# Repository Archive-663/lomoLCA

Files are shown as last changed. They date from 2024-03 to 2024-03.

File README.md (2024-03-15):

# Lot no. 016 | A rehousing Lomo LC-A 32mm Minitar lens for mirrorless

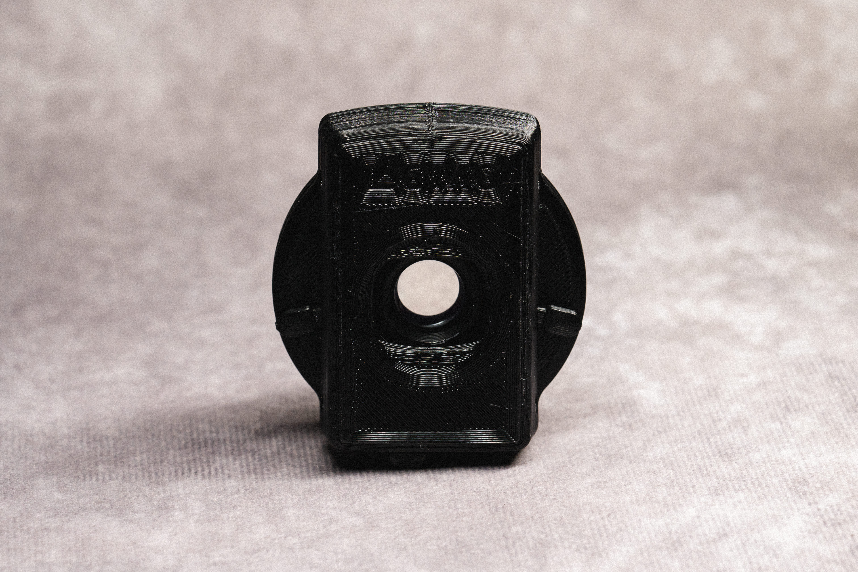
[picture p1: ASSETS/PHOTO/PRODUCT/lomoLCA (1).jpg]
productPhoto001

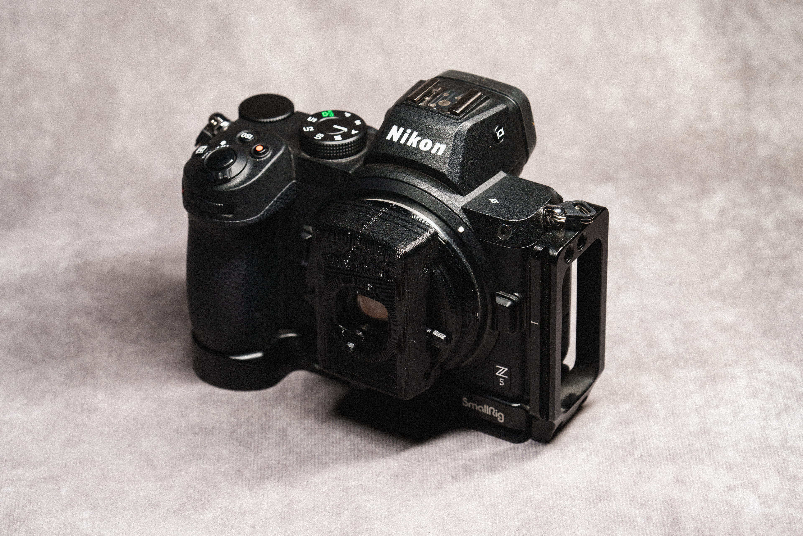
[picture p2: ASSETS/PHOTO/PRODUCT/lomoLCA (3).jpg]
productPhoto002

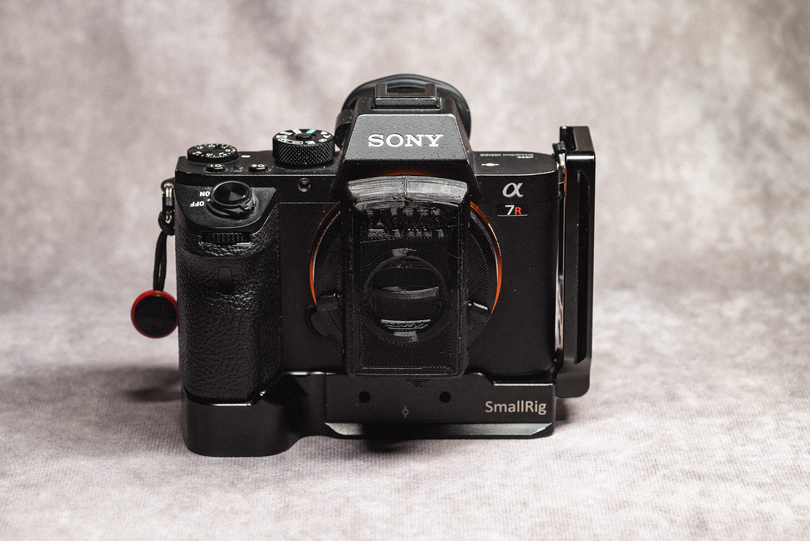
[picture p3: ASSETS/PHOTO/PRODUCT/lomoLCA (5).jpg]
productPhoto003

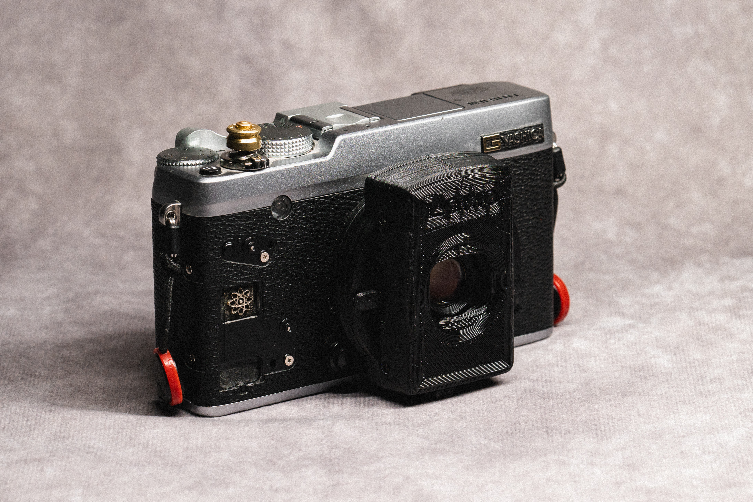
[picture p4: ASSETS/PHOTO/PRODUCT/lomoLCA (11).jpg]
productPhoto004


### In this repository:
- [Lomo LC-A Main Rehousing](https://github.com/Archive-663/lomoLCA/tree/main/Lomo%20LCA%20Main%20Rehousing)
- [Sony E-Mount](https://github.com/Archive-663/lomoLCA/tree/main/Sony%20E-mount)
- [Canon RF-Mount](https://github.com/Archive-663/lomoLCA/tree/main/Canon%20RF-mount)
- [Fuji X-Mount](https://github.com/Archive-663/lomoLCA/tree/main/Fuji%20X-mount)
- [Nikon Z-Mount](https://github.com/Archive-663/lomoLCA/tree/main/Nikon%20Z-mount)

### How to use this Repo:
Download the Main Housing and then the mount you have. You can pick up <a href="https://github.com/Archive-663/lensMounts" target='_blank'>rear lens caps here.</a>

### Accompanying video:
<a href='https://www.youtube.com/watch?v=eCiiPDMJ1F8' target='_blank'>004 / / the one where i ask you to come back here at six in the morning and call my name twice</a>

### Background Story:
I always liked the camera body of the Lomo LC-A and I didn't enjoy how expensive the Lomography Minitar lens was. I wanted to replicate the experience of shooting with the LC-A with sliding lens cover, and lever acuated aperture and focus. I picked up a lens assembly from a broken LC-A and started working on translating the LC-A's sliding lens cover and once I figured that out I applied the same assembly to the aperture as space was limited. I could have easily made an iris but there was not enough room to allow for multiple mounts.

If you have a broken LC-A you can put the lens to good use now with this rehousing. It's a pretty simple print with minimal post processing.

### Samples:
samplePhoto001
samplePhoto002
samplePhoto003
samplePhoto004

### Help support Archive 663 with a dontation or monthly sub



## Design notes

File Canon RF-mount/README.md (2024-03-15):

# Lot no. 016 | Lomo LC-A Canon RF-Mount

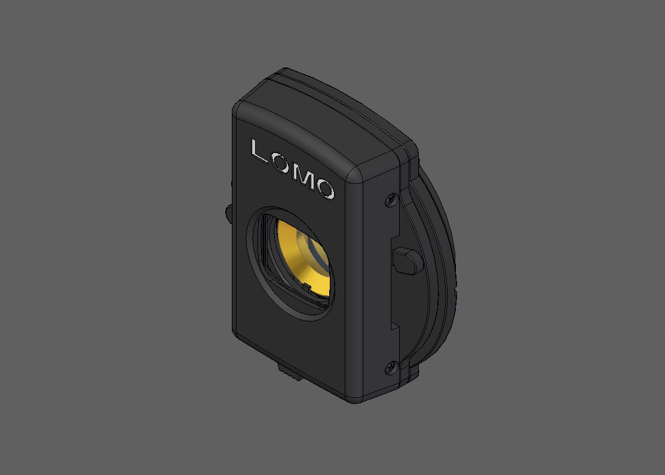
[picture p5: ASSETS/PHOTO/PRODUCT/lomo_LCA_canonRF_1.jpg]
productPhoto001

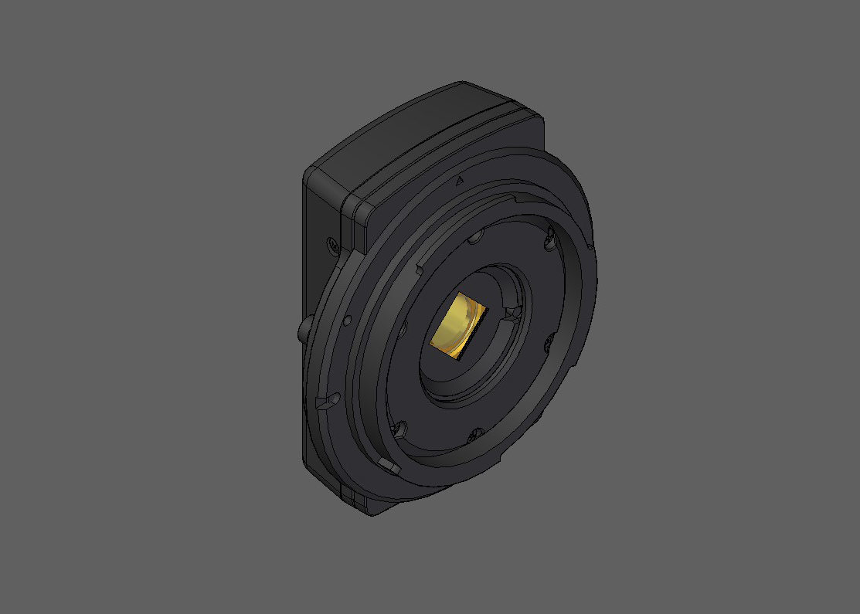
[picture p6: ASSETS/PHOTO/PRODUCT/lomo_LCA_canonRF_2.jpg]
productPhoto002


### What you'll need:
- 6x M1.6 x 5mm pan head screws (PETG) or self-tappin screws (ABS or PETG)
- 1x M1.6 tap

### What would be helpful:
- M1.4 drill bit
- M1.8/M2 drill bit
- Micro files
- PTFE synthetic grease

### Printing help:
Filament recommendation:
- ABS
- PETG

Generally, all my designs have chamfers on the print face of the STL. You can reference the supplied 'printOrientationFile.3mf' files for suggested print orientation.

### Assembly help:
Drill holes to their correct tap size before tapping.
- M1.6 requires M1.4 bore followed by an M1.6 tap.
- M1.8 or M2 bore for screw holes that aren't tapped.

- Specifically for the Canon RF mount you need to replace the 'lensBase_Mount' with the 'canonRF_mount'

Test fit before assembling. Will need to file parts to allow free movement. You may need to drill out the original mounting holes on the Minitar lens assembly for the m1.6 screws to fit. 

Lightly grease the inside of the mount cap.

To assemble correctly, please view the _assembly.stp file for help in parts orientation. If you do not have a CAD program, <a href="https://www.freecad.org/downloads.php" target="_blank">download FreeCAD</a> to view the assembly file and better understand how it should assemble. If using FreeCAD, the naming conventions should carry over and you will be able to see which lens element you need from the various smartphone lenses. (Verified in FreeCAD 0.18) If using something like Solid Edge open the file as an assembly to retain the names of the parts.

### Help support Archive 663 with a dontation or monthly sub



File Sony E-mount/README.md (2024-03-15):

# Lot no. 016 | Lomo LC-A Sony E-Mount

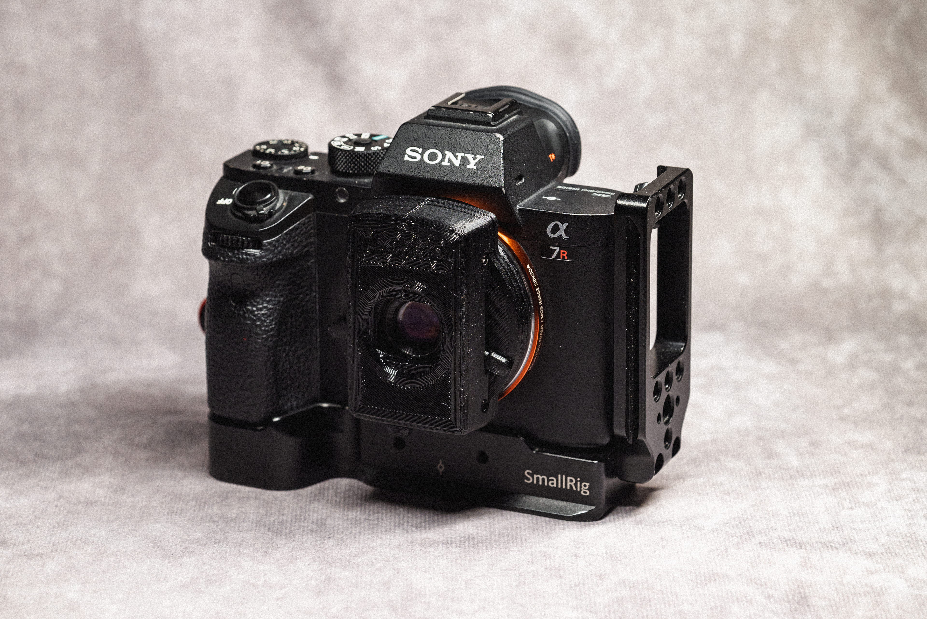
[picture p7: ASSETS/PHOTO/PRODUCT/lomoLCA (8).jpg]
productPhoto001

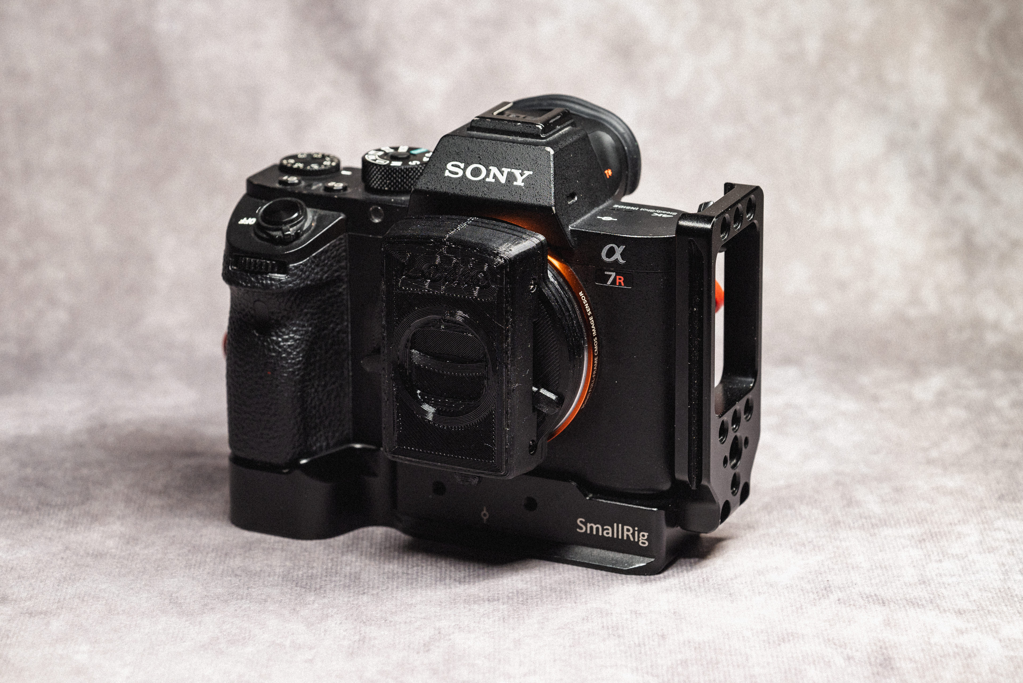
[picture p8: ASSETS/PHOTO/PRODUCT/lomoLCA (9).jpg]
productPhoto002


### What you'll need:
- 6x M1.6 x 5mm pan head screws (PETG) or self-tappin screws (ABS or PETG)
- 1x M1.6 tap

### What would be helpful:
- M1.4 drill bit
- M1.8/M2 drill bit
- Micro files
- PTFE synthetic grease

### Printing help:
Filament recommendation:
- ABS
- PETG

Generally, all my designs have chamfers on the print face of the STL. You can reference the supplied 'printOrientationFile.3mf' files for suggested print orientation.

### Assembly help:
Drill holes to their correct tap size before tapping.
- M1.6 requires M1.4 bore followed by an M1.6 tap.
- M1.8 or M2 bore for screw holes that aren't tapped.

Test fit before assembling. Will need to file parts to allow free movement. You may need to drill out the original mounting holes on the Minitar lens assembly for the m1.6 screws to fit. 

Lightly grease the inside of the mount cap where the aperture clutch runs.

To assemble correctly, please view the _assembly.stp file for help in parts orientation. If you do not have a CAD program, <a href="https://www.freecad.org/downloads.php" target="_blank">download FreeCAD</a> to view the assembly file and better understand how it should assemble. If using FreeCAD, the naming conventions should carry over and you will be able to see which lens element you need from the various smartphone lenses. (Verified in FreeCAD 0.18) If using something like Solid Edge open the file as an assembly to retain the names of the parts.

### Help support Archive 663 with a dontation or monthly sub



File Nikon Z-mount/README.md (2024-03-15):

# Lot no. 016 | Lomo LC-A Nikon Z-Mount

productPhoto001
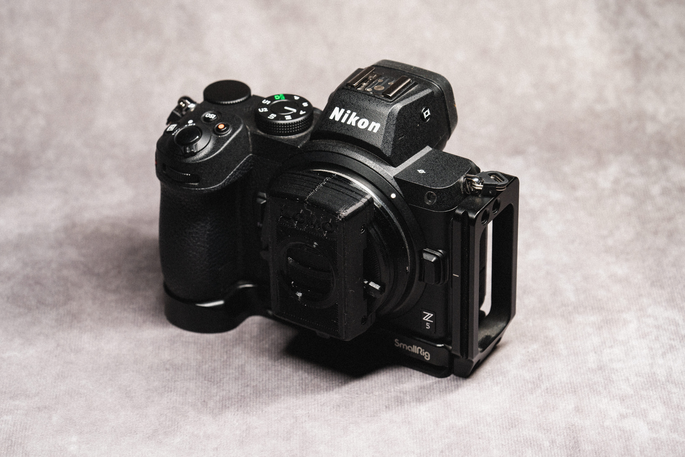
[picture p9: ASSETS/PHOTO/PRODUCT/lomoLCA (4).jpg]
productPhoto002


### What you'll need:
- 12x M1.6 x 5mm pan head screws (PETG) or self-tappin screws (ABS or PETG)
- 1x M1.6 tap

### What would be helpful:
- M1.4 drill bit
- M1.8/M2 drill bit
- Micro files
- PTFE synthetic grease

### Printing help:
Filament recommendation:
- ABS
- PETG

Generally, all my designs have chamfers on the print face of the STL. You can reference the supplied 'printOrientationFile.3mf' files for suggested print orientation.

### Assembly help:
Drill holes to their correct tap size before tapping.
- M1.6 requires M1.4 bore followed by an M1.6 tap.
- M1.8 or M2 bore for screw holes that aren't tapped.

Test fit before assembling. Will need to file parts to allow free movement. You may need to drill out the original mounting holes on the Minitar lens assembly for the m1.6 screws to fit. 

Lightly grease the inside of the mount where the aperture clutch runs.

To assemble correctly, please view the _assembly.stp file for help in parts orientation. If you do not have a CAD program, <a href="https://www.freecad.org/downloads.php" target="_blank">download FreeCAD</a> to view the assembly file and better understand how it should assemble. If using FreeCAD, the naming conventions should carry over and you will be able to see which lens element you need from the various smartphone lenses. (Verified in FreeCAD 0.18) If using something like Solid Edge open the file as an assembly to retain the names of the parts.

### Help support Archive 663 with a dontation or monthly sub



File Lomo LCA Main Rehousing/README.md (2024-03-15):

# Lot no. 016 | Lomo LC-A Main Rehousing

productPhoto001
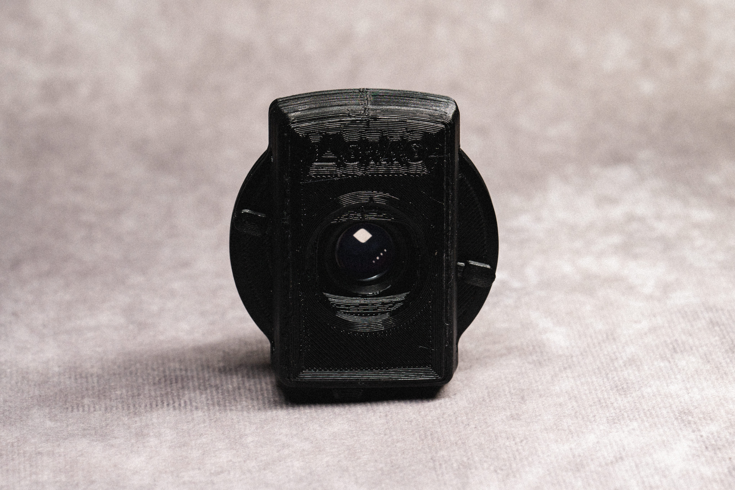
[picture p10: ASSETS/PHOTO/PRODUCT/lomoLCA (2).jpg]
productPhoto002

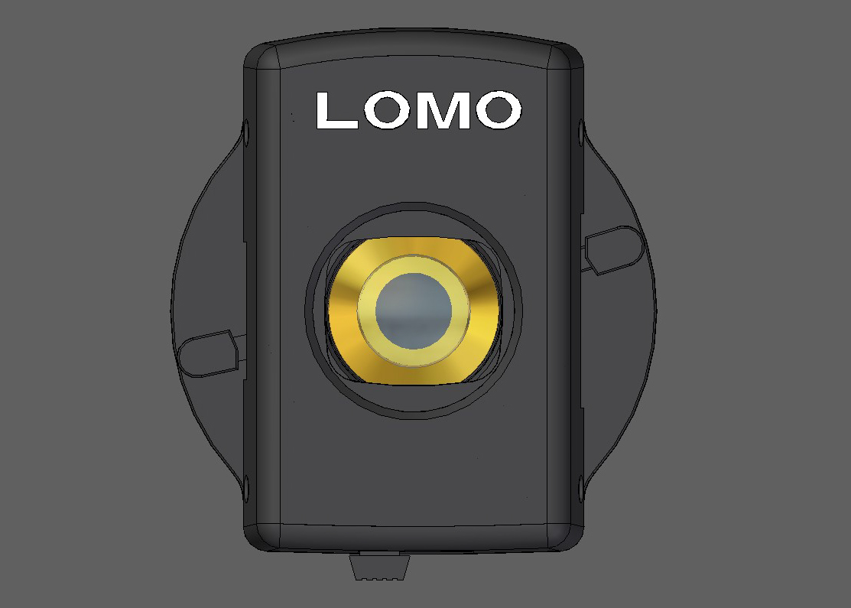
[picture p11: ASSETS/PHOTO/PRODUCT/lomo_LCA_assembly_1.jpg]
productPhoto003

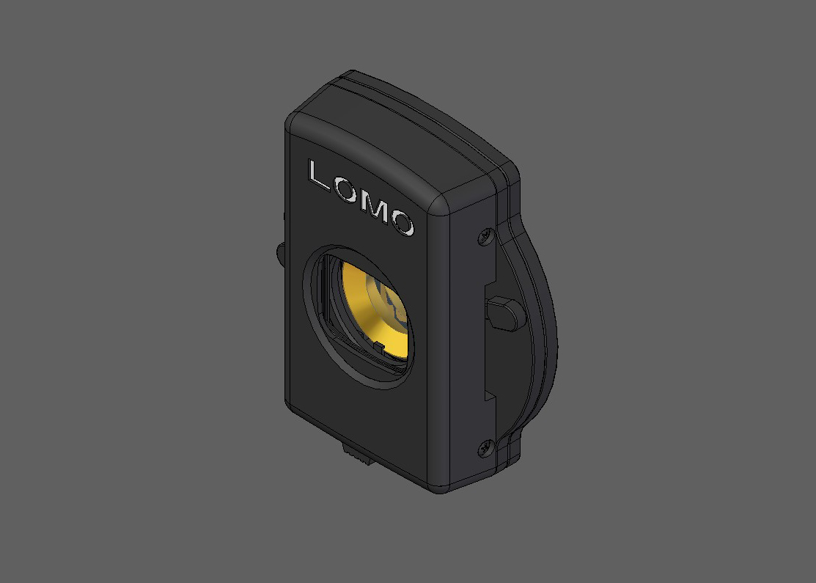
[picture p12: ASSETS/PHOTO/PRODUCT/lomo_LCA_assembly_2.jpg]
productPhoto004

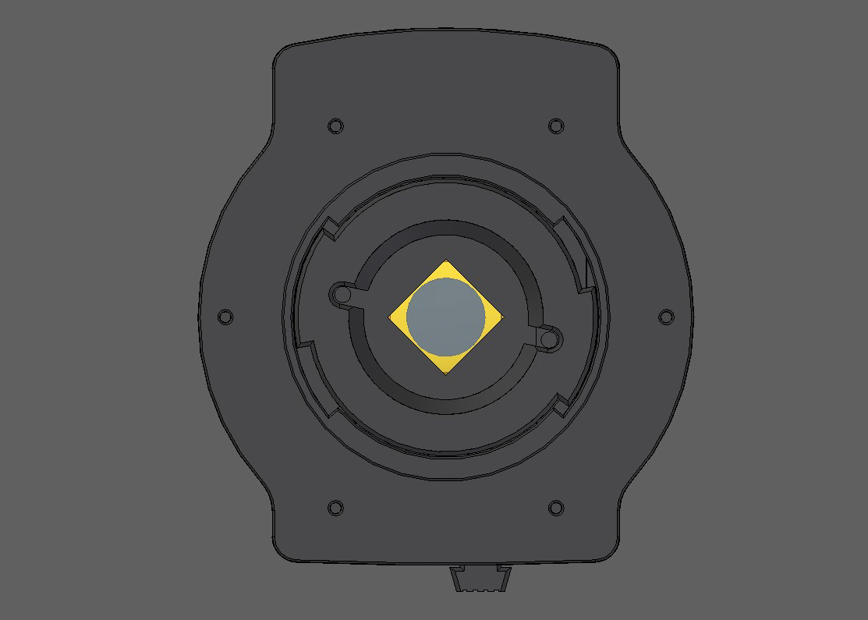
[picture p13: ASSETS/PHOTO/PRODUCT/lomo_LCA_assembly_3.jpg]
productPhoto005


### Features:
- Iconic Sliding Lens Cover
- Lever actuated Aperture and Focus
- Standard LOMO or classic ЛОМО face plate

### What you'll need:
- 15x M1.6 x 5mm pan head screws (PETG) or self-tappin screws (ABS or PETG)
- 1x M1.6 tap

### What would be helpful:
- M1.4 drill bit
- M1.8/M2 drill bit
- Micro files
- PTFE synthetic grease

### Printing help:
Filament recommendation:
- ABS
- PETG

Generally, all my designs have chamfers on the print face of the STL. You can reference the supplied 'printOrientationFile.3mf' files for suggested print orientation.

### Assembly help:
Drill holes to their correct tap size before tapping.
- M1.6 requires M1.4 bore followed by an M1.6 tap.
- M1.8 or M2 bore for screw holes that aren't tapped.

Test fit before assembling. Will need to file parts to allow free movement. You may need to drill out the original mounting holes on the Minitar lens assembly for the m1.6 screws to fit.

Lightly grease the shutter and aperture tracks and the blades.

To assemble correctly, please view the _assembly.stp file for help in parts orientation. If you do not have a CAD program, <a href="https://www.freecad.org/downloads.php" target="_blank">download FreeCAD</a> to view the assembly file and better understand how it should assemble. If using FreeCAD, the naming conventions should carry over and you will be able to see which lens element you need from the various smartphone lenses. (Verified in FreeCAD 0.18) If using something like Solid Edge open the file as an assembly to retain the names of the parts.

### Help support Archive 663 with a dontation or monthly sub



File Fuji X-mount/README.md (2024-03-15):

# Lot no. 016 | Lomo LC-A Fuji X-Mount

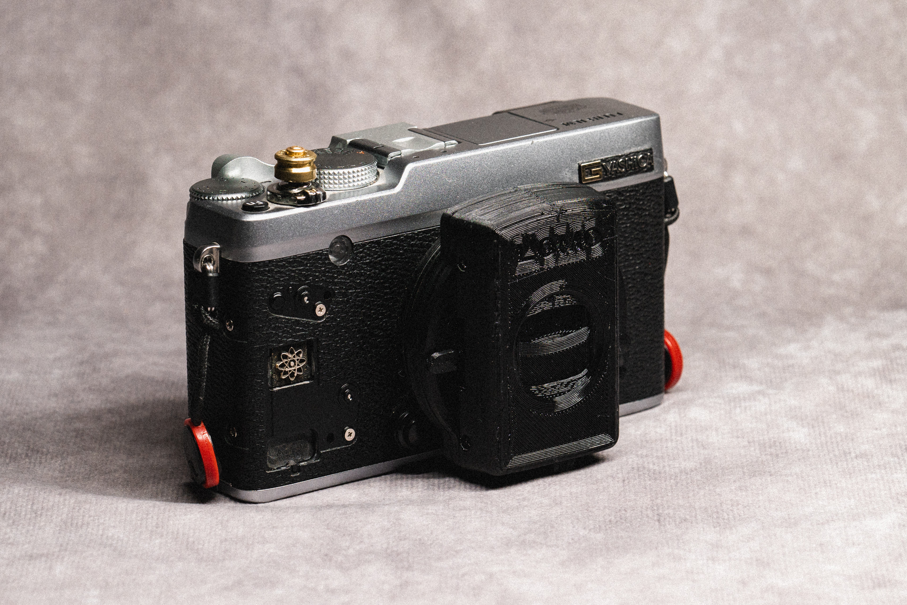
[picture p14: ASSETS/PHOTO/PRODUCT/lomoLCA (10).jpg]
productPhoto001

productPhoto002
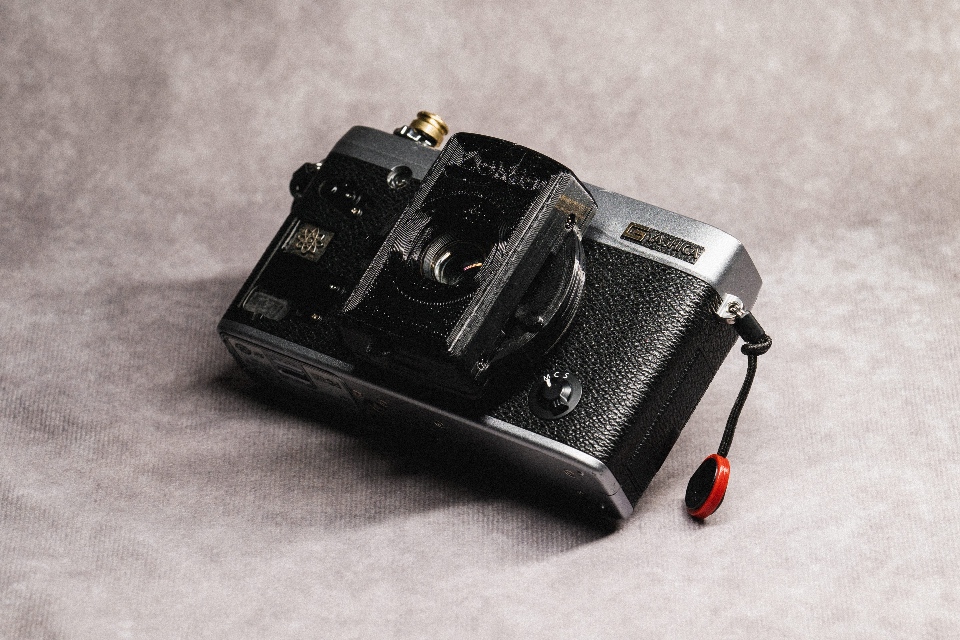
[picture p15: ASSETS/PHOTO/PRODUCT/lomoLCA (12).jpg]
productPhoto003

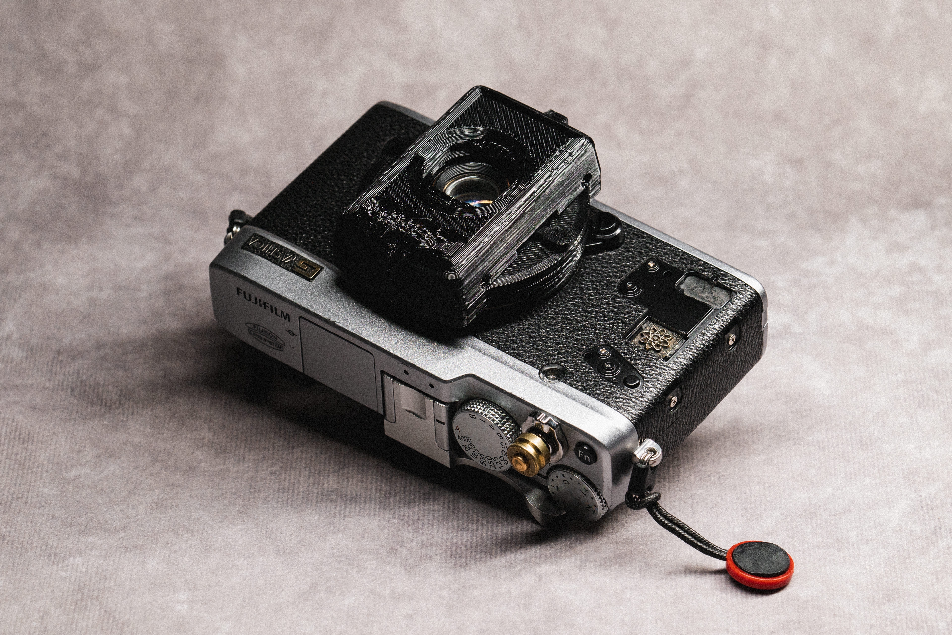
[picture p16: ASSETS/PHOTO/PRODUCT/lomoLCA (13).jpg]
productPhoto004


### What you'll need:
- 6x M1.6 x 5mm pan head screws (PETG) or self-tappin screws (ABS or PETG)
- 1x M1.6 tap

### What would be helpful:
- M1.4 drill bit
- M1.8/M2 drill bit
- Micro files
- PTFE synthetic grease

### Printing help:
Filament recommendation:
- ABS
- PETG

Generally, all my designs have chamfers on the print face of the STL. You can reference the supplied 'printOrientationFile.3mf' files for suggested print orientation.

### Assembly help:
Drill holes to their correct tap size before tapping.
- M1.6 requires M1.4 bore followed by an M1.6 tap.
- M1.8 or M2 bore for screw holes that aren't tapped.

Test fit before assembling. Will need to file parts to allow free movement. You may need to drill out the original mounting holes on the Minitar lens assembly for the m1.6 screws to fit. 

Lightly grease the inside of the mount where the aperture clutch runs.

To assemble correctly, please view the _assembly.stp file for help in parts orientation. If you do not have a CAD program, <a href="https://www.freecad.org/downloads.php" target="_blank">download FreeCAD</a> to view the assembly file and better understand how it should assemble. If using FreeCAD, the naming conventions should carry over and you will be able to see which lens element you need from the various smartphone lenses. (Verified in FreeCAD 0.18) If using something like Solid Edge open the file as an assembly to retain the names of the parts.

### Help support Archive 663 with a dontation or monthly sub



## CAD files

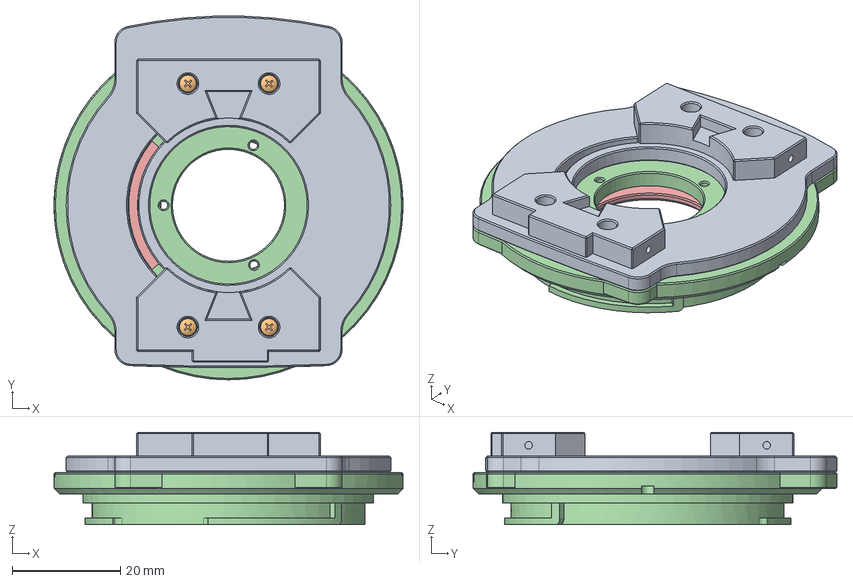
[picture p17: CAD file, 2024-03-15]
Canon RF-mount/STEP/lomo_LCA_canonRF_mount_assembly.stp
64.5 x 67.2 x 17.0 mm
lomo_LCA_lensBase
M1.6_panHead_5mm x 10
lomo_LCA_canonRF_mount

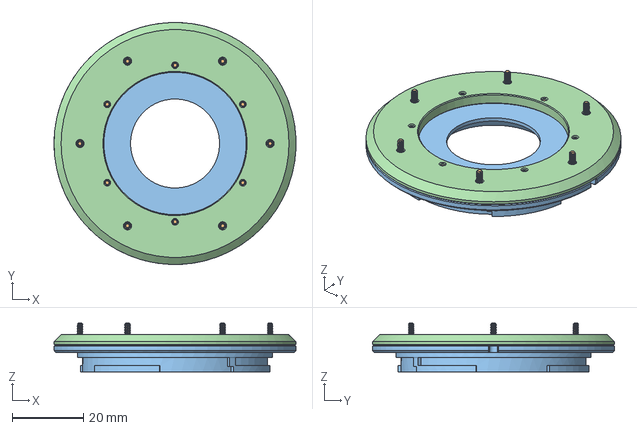
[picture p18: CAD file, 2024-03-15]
Nikon Z-mount/STEP/lomo_LCA_nikonZ_mount_assembly.stp
68.0 x 68.0 x 13.8 mm
M1.6_panHead_5mm x 12
lomo_LCA_nikonZ_mount

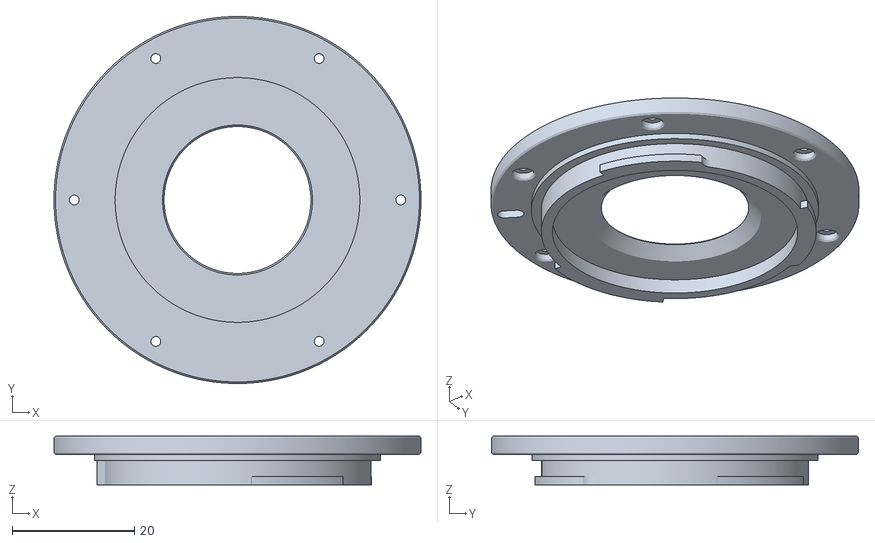
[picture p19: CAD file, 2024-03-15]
Sony E-mount/STL/lomo_LCA_sonyE_mount_complete.stl
60.0 x 60.0 x 8.00

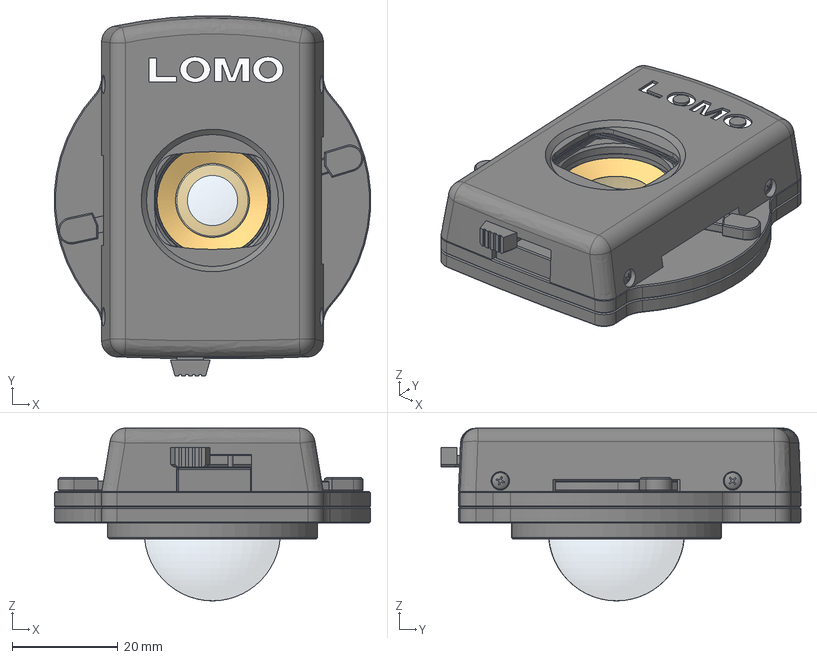
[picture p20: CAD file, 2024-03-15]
Lomo LCA Main Rehousing/STEP/lomo_LCA_assembly.stp
59.9 x 68.2 x 32.7 mm
lomo_LCA_lensMinitar
lomo_LCA_lensBase
M1.6_panHead_5mm x 15
lomo_LCA_focusRing
lomo_LCA_focusLock
lomo_LCA_apertureBlade_2
lomo_LCA_apertureBlade_1
lomo_LCA_apertureClutch
lomo_LCA_apertureLever
lomo_LCA_shutterTrack
lomo_LCA_lensBase_mount
lomo_LCA_shutterClutch
lomo_LCA_shutterClutchSlide
lomo_LCA_shutterTrack_cap
lomo_LCA_lensFacePlate_LOMO
lomo_LCA_lensShutter_1
lomo_LCA_lensShutter_2

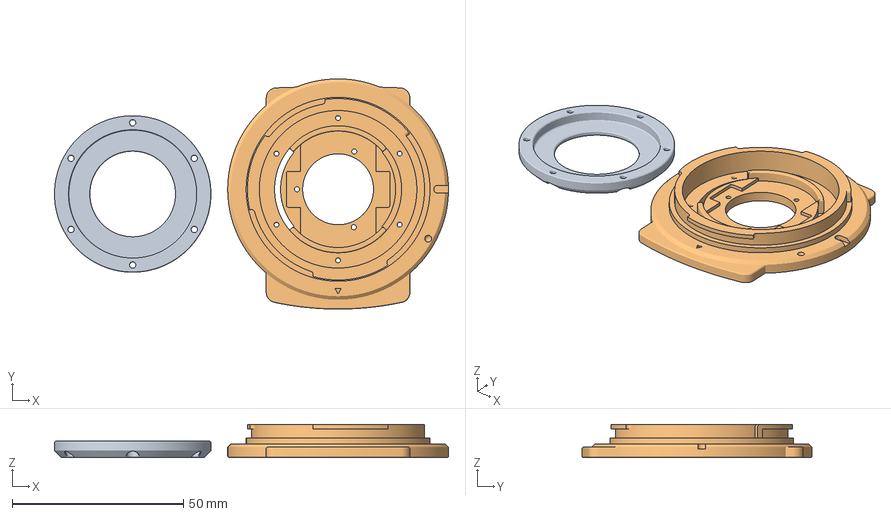
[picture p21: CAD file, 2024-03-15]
Canon RF-mount/STL/lomo_LCA_canonRF_mount_printOrientationFile.3mf
115.1 x 67.2 x 9.65 mm
lomo_LCA_canonRF_mount_cap.stl
lomo_LCA_canonRF_mount.stl

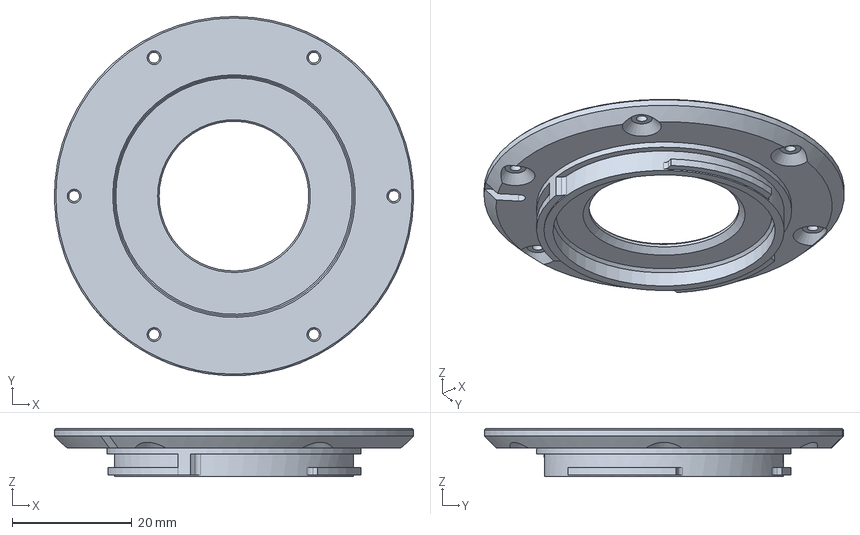
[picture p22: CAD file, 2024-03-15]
Fuji X-mount/STEP/lomo_LCA_fujiX_mount.stp
60.0 x 60.0 x 8.05 mm

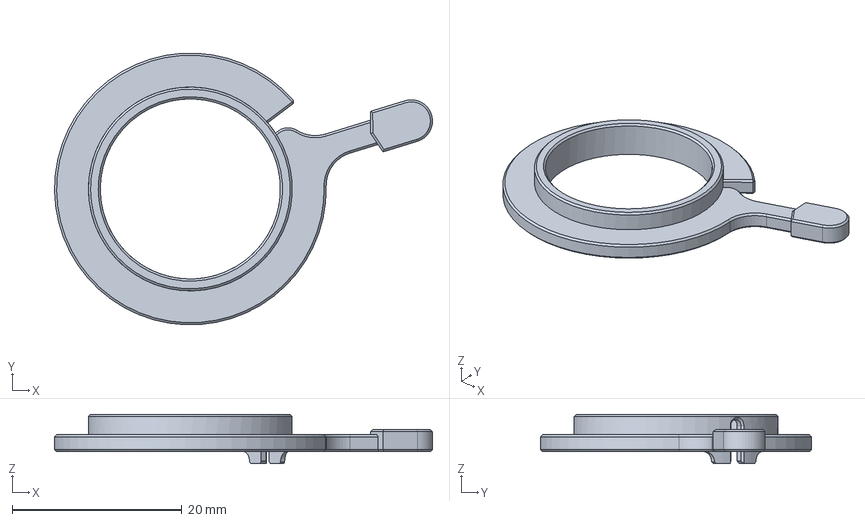
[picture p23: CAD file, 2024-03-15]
Lomo LCA Main Rehousing/STEP/lomo_LCA_focusRing.stp
44.5 x 32.0 x 5.83 mm

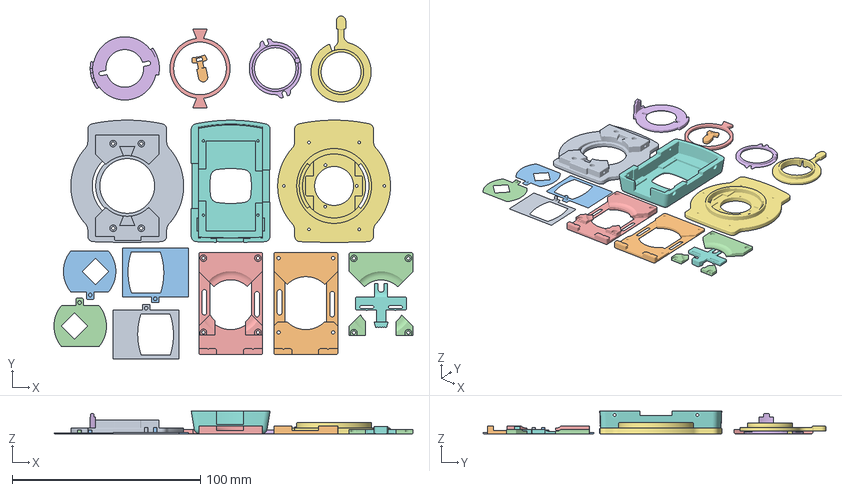
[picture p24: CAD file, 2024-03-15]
Lomo LCA Main Rehousing/STL/lomo_LCA_rehousing_printOrientationFile.3mf
190.9 x 182.4 x 12.0 mm
lomo_LCA_lensBase.stl
lomo_LCA_apertureLever.stl
lomo_LCA_apertureBlade_1.stl
lomo_LCA_apertureBlade_2.stl
lomo_LCA_focusLock.stl
lomo_LCA_apertureClutch.stl
lomo_LCA_focusRing.stl
lomo_LCA_shutterClutchSlide.stl
lomo_LCA_lensShutter_1.stl
lomo_LCA_shutterTrack_base.stl
lomo_LCA_lensShutter_2.stl
lomo_LCA_shutterTrack_cap.stl
lomo_LCA_shutterTrack.stl
lomo_LCA_shutterClutch.stl
lomo_LCA_lensBase_mount.stl
lomo_LCA_lensFacePlate_LOMO.stl

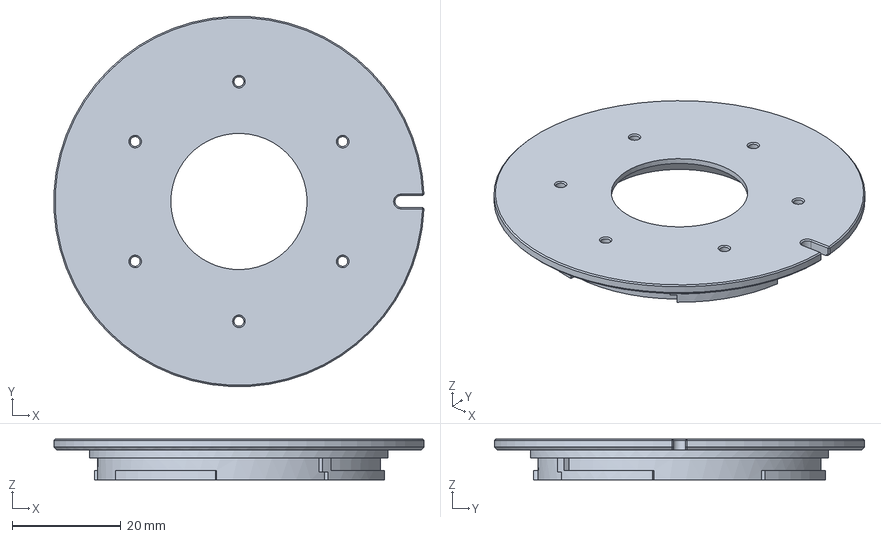
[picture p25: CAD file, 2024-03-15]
Nikon Z-mount/STEP/lomo_LCA_nikonZ_mount.stp
67.9 x 67.9 x 7.50 mm

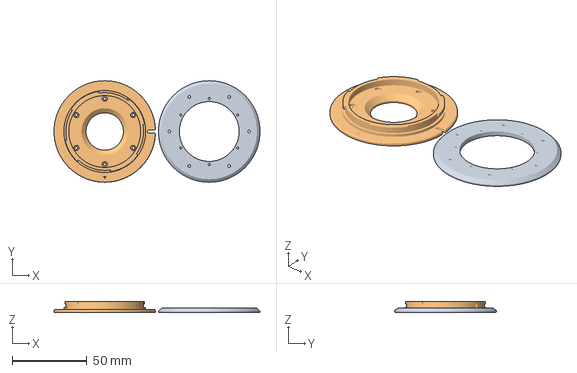
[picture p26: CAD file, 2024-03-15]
Nikon Z-mount/STL/lomo_LCA_nikonZ_mount_printOrientationFile.3mf
138.0 x 68.0 x 7.50 mm
lomo_LCA_nikonZ_cap.stl
lomo_LCA_nikonZ_mount.stl

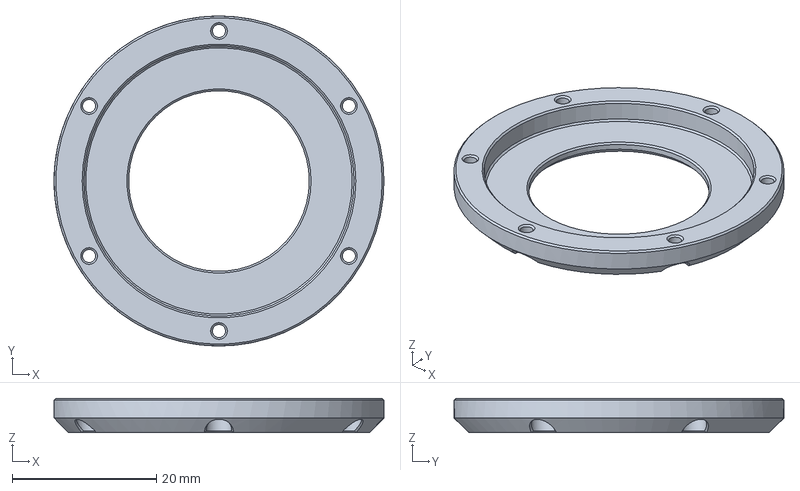
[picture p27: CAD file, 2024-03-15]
Canon RF-mount/STEP/lomo_LCA_canonRF_mount_cap.stp
45.7 x 45.7 x 4.75 mm

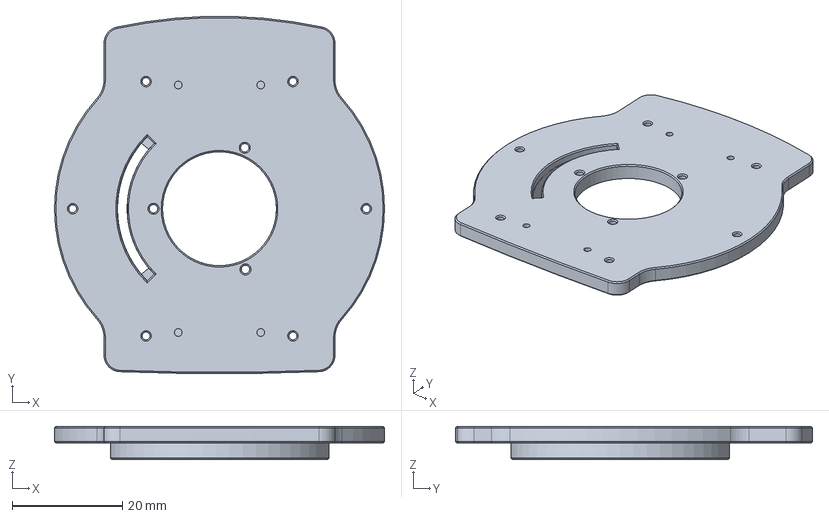
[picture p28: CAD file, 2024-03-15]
Lomo LCA Main Rehousing/STEP/lomo_LCA_lensBase_mount.stp
60.0 x 64.9 x 6.00 mm

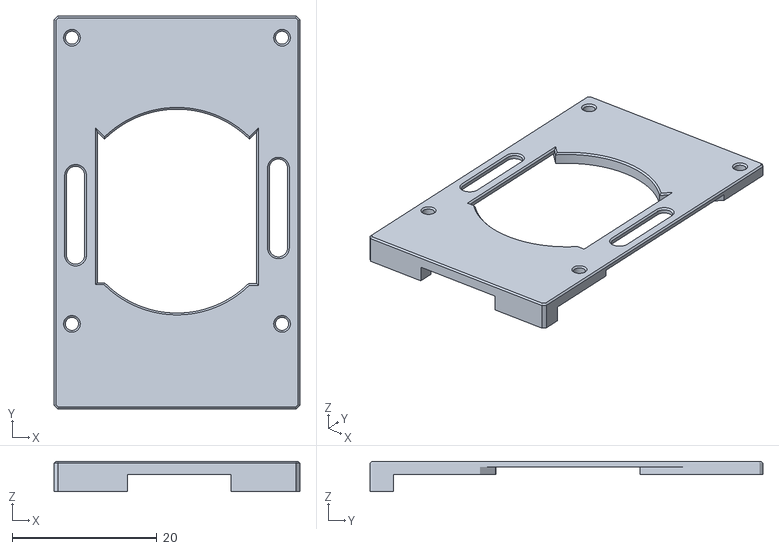
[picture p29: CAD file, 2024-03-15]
Lomo LCA Main Rehousing/STL/lomo_LCA_shutterTrack_base.stl
33.9 x 54.2 x 4.20

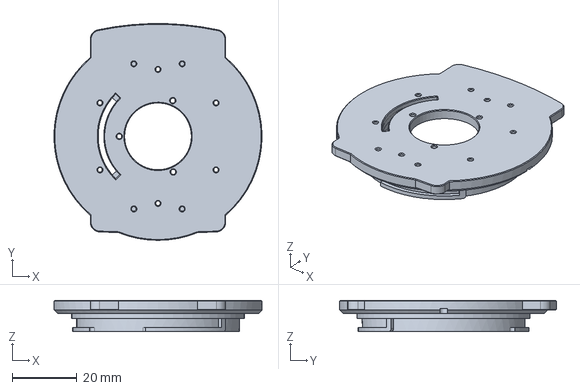
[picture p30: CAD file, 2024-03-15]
Canon RF-mount/STEP/lomo_LCA_canonRF_mount.stp
64.5 x 67.2 x 9.65 mm

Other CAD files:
Fuji X-mount/STL/lomo_LCA_fujiX_mount_printOrientationFile.3mf
Sony E-mount/STEP/lomo_LCA_sonyE_mount.stp
Sony E-mount/STL/lomo_LCA_sonyE_mount_printOrientationFile.3mf
Lomo LCA Main Rehousing/STEP/lomo_LCA_lensBase.stp
Canon RF-mount/STL/lomo_LCA_canonRF_mount.stl
Canon RF-mount/STL/lomo_LCA_canonRF_mount_cap.stl
Fuji X-mount/STL/lomo_LCA_fujiX_mount.stl
Lomo LCA Main Rehousing/STEP/lomo_LCA_apertureBlade_1.stp
Lomo LCA Main Rehousing/STEP/lomo_LCA_apertureBlade_2.stp
Lomo LCA Main Rehousing/STEP/lomo_LCA_apertureClutch.stp
Lomo LCA Main Rehousing/STEP/lomo_LCA_apertureLever.stp
Lomo LCA Main Rehousing/STEP/lomo_LCA_focusLock.stp
Lomo LCA Main Rehousing/STEP/lomo_LCA_lensFacePlate_LОМО.stp
Lomo LCA Main Rehousing/STEP/lomo_LCA_lensFacePlate_ЛОМО.stp
Lomo LCA Main Rehousing/STEP/lomo_LCA_lensShutter_1.stp
Lomo LCA Main Rehousing/STEP/lomo_LCA_lensShutter_2.stp
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
